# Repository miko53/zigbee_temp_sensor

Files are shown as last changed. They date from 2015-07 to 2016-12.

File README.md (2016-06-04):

# zigbee temperature sensor

This repository contains project about a temperature sensor based on Xbee device.
It will be coupled with the zigbee controler and the web_monitoring projets to resp. retrieve the value from the sensor 
and display thought a web site.

## Hardware part
The hardware folder groups schematics. it is based on a PIC device (PIC18LF2420) coupled with a XBee module (from Digi)
Temperature and Humidity sensor is a HYT221

## Firmware part
The folder contains source code to build the firmware for the PIC device.

## Features
 - read temperature and humidity around each minutes
 - read the battery voltage
 - PIC clock calibration
Most of 
 
##### Note:
 - acquisition period will be reviewed to improve consumption
 
autonomy test on going, with hourly reception of battery value and reception of temp/humidity each minutes
 - estimation: more than 6 months if I interpolate the current consumption.

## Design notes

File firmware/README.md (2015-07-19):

 zigbee_temp_sensor
code for manage temperature and humidity sensor with a PIC device and a Zigbee (Xbee device)

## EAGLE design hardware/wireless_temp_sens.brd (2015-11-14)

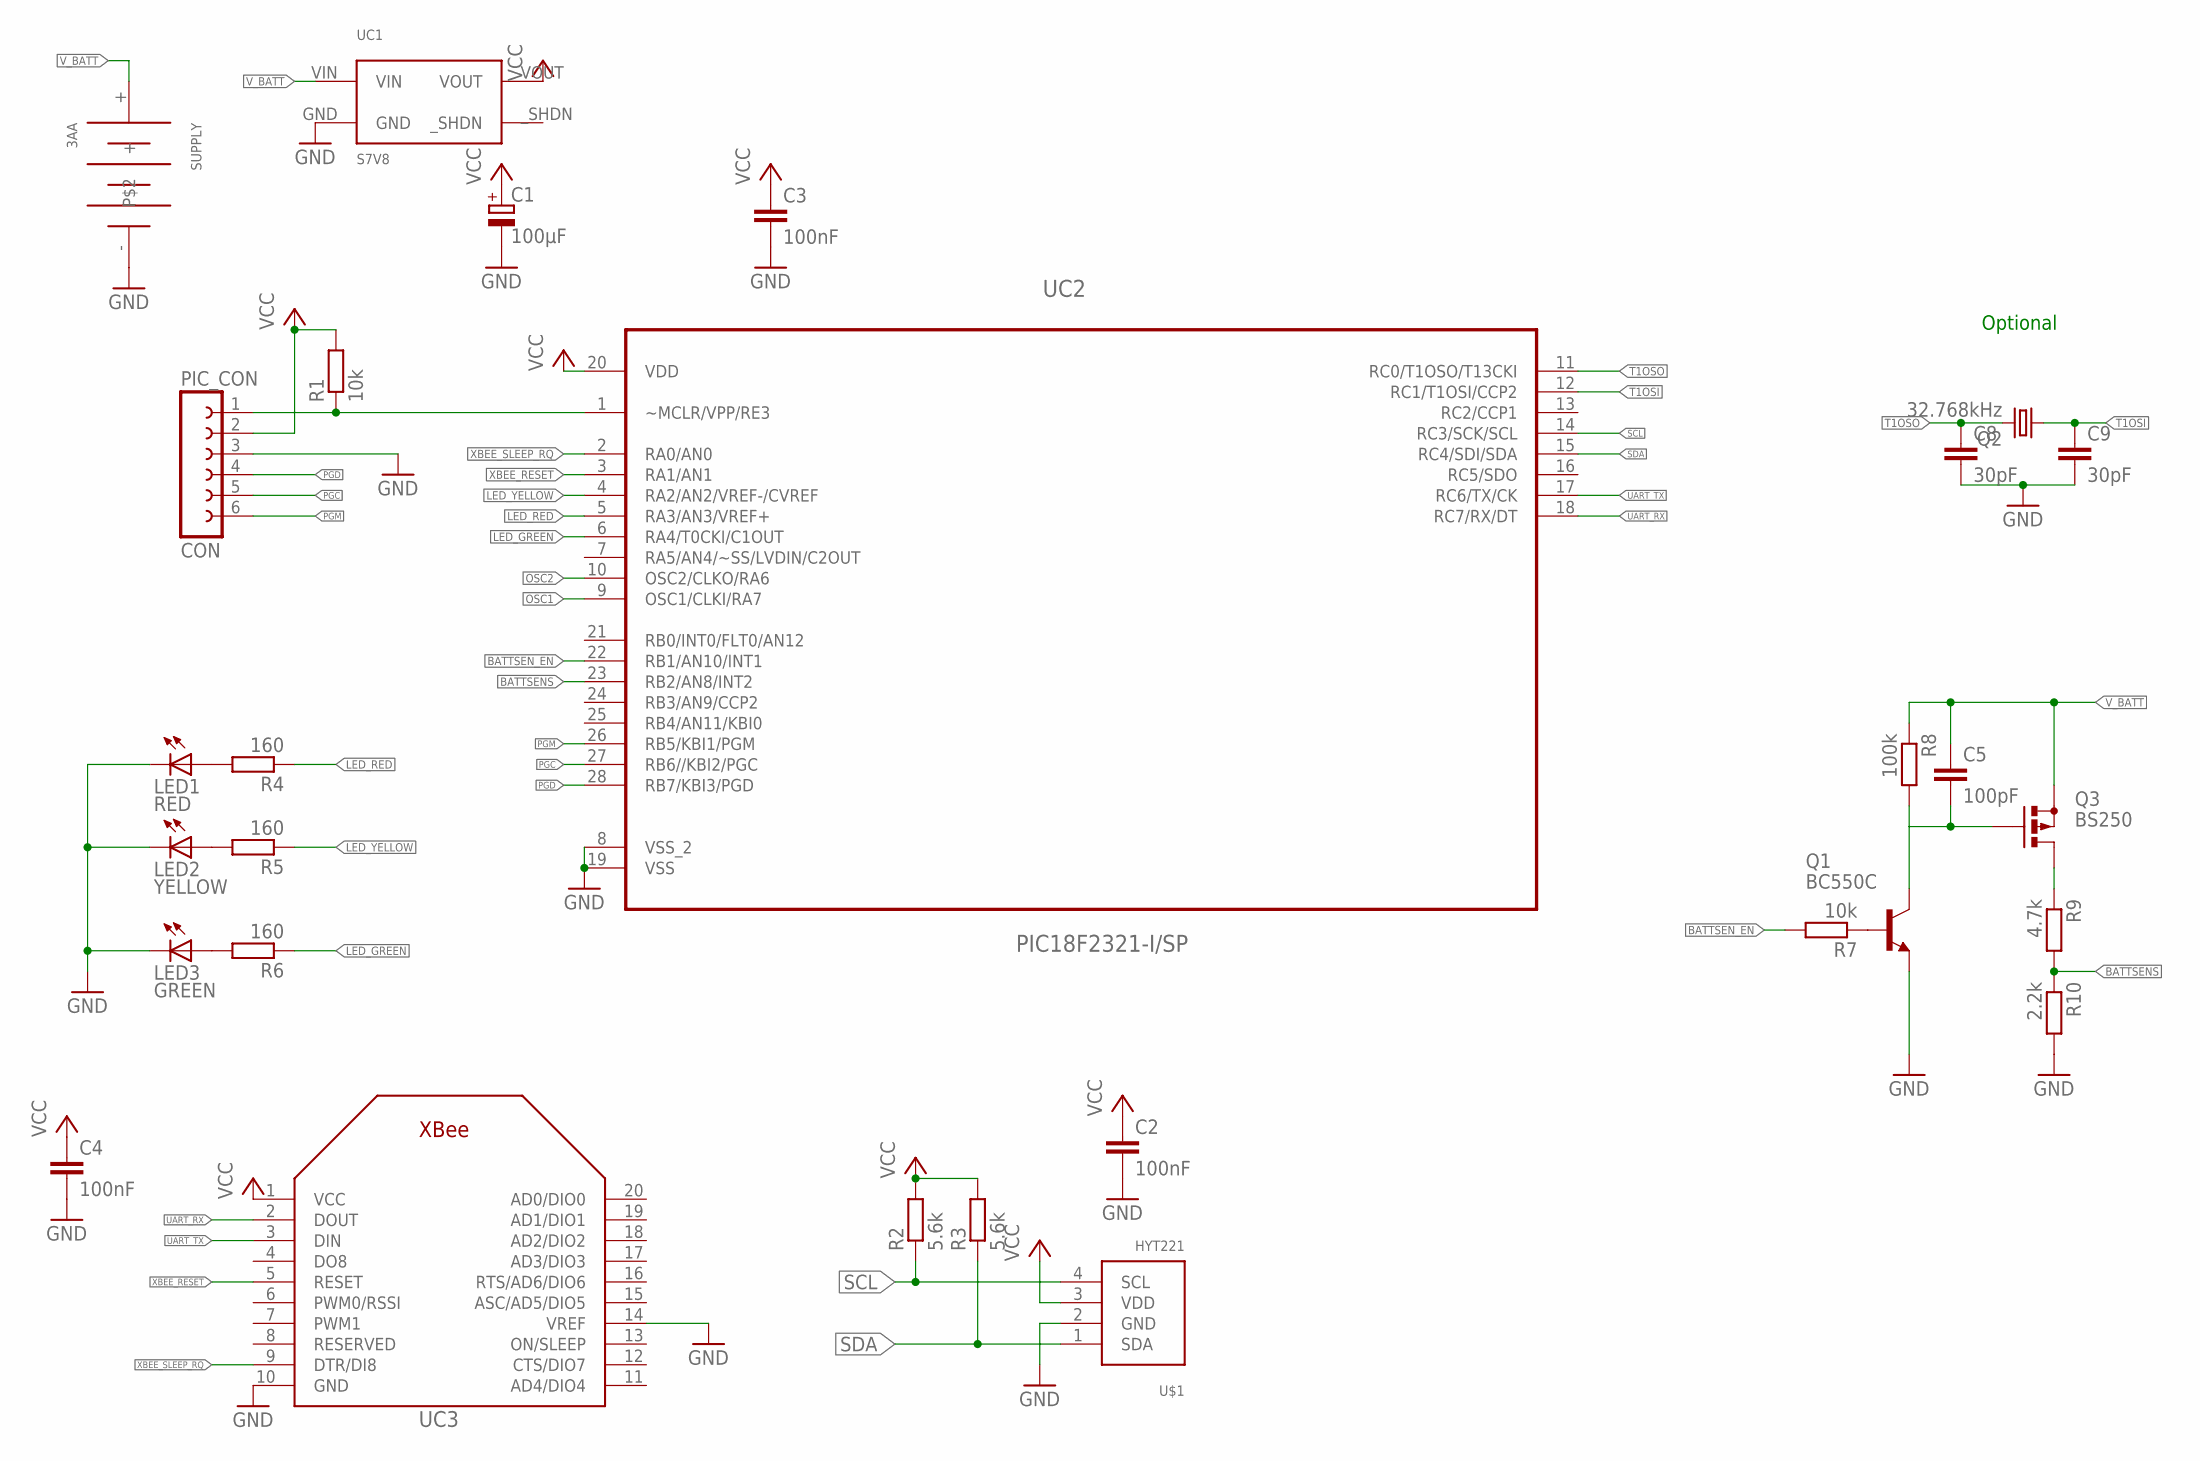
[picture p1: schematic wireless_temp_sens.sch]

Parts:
C1: 100µF; E2,5-6
C2, C3, C4: 100nF; C025-025X050
C5: 100pF; C025-025X050
C8, C9: 30pF; C025-024X044
CON: PIC_CON; FE06
LED1: RED; LED3MM
LED2: YELLOW; LED3MM
LED3: GREEN; LED3MM
Q1: BC550C; TO92-EBC
Q2: 32.768kHz; TC26H
Q3: BS250; SOT54E
R1, R7: 10k; 0204/7
R2, R3: 5.6k; 0204/7
R4, R5, R6: 160; 0204/7
R8: 100k; 0204/7
R9: 4.7k; 0204/7
R10: 2.2k; 0204/7
SUPPLY: 3AA; LR6-R6-R6P
U$1: HYT221HYT221-CON; HYT221-CON
UC1: S7V8; S7V8_P
UC2: PIC18F2321-I/SP; DIP254P762X508-28
UC3: XBEE

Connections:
BATTSENS: R9.2, R10.1, UC2.23 (RB2/AN8/INT2)
BATTSEN_EN: R7.2, UC2.22 (RB1/AN10/INT1)
GND: C1.-, C2.2, C3.2, C4.2, C8.2, C9.2, CON.3, LED1.K (C), LED2.K (C), LED3.K (C), Q1.E, R10.2, SUPPLY.-, U$1.2 (GND), UC1.GND, UC2.8 (VSS_2), UC2.19 (VSS), UC3.10 (GND), UC3.14 (VREF)
LED_GREEN: R6.1, UC2.6 (RA4/T0CKI/C1OUT)
LED_RED: R4.1, UC2.5 (RA3/AN3/VREF+)
LED_YELLOW: R5.1, UC2.4 (RA2/AN2/VREF-/CVREF)
unnamed: Q1.B, R7.1
unnamed: CON.1, R1.1, UC2.1 (~MCLR/VPP/RE3)
unnamed: Q3.D, R9.1
unnamed: C5.2, Q1.C, Q3.G, R8.2
unnamed: LED1.A, R4.2
unnamed: LED2.A, R5.2
unnamed: LED3.A, R6.2
OSC1: UC2.9 (OSC1/CLKI/RA7)
OSC2: UC2.10 (OSC2/CLKO/RA6)
PGC: CON.5, UC2.27 (RB6//KBI2/PGC)
PGD: CON.4, UC2.28 (RB7/KBI3/PGD)
PGM: CON.6, UC2.26 (RB5/KBI1/PGM)
SCL: R2.1, U$1.4 (SCL), UC2.14 (RC3/SCK/SCL)
SDA: R3.1, U$1.1 (SDA), UC2.15 (RC4/SDI/SDA)
T1OSI: C9.1, Q2.1, UC2.12 (RC1/T1OSI/CCP2)
T1OSO: C8.1, Q2.2, UC2.11 (RC0/T1OSO/T13CKI)
UART_RX: UC2.18 (RC7/RX/DT), UC3.2 (DOUT)
UART_TX: UC2.17 (RC6/TX/CK), UC3.3 (DIN)
VCC: C1.+, C2.1, C3.1, C4.1, CON.2, R1.2, R2.2, R3.2, U$1.3 (VDD), UC1.VOUT, UC2.20 (VDD), UC3.1 (VCC)
V_BATT: C5.1, Q3.S, R8.1, SUPPLY.+, UC1.VIN
XBEE_RESET: UC2.3 (RA1/AN1), UC3.5 (RESET)
XBEE_SLEEP_RQ: UC2.2 (RA0/AN0), UC3.9 (DTR/DI8)

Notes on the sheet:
Optional

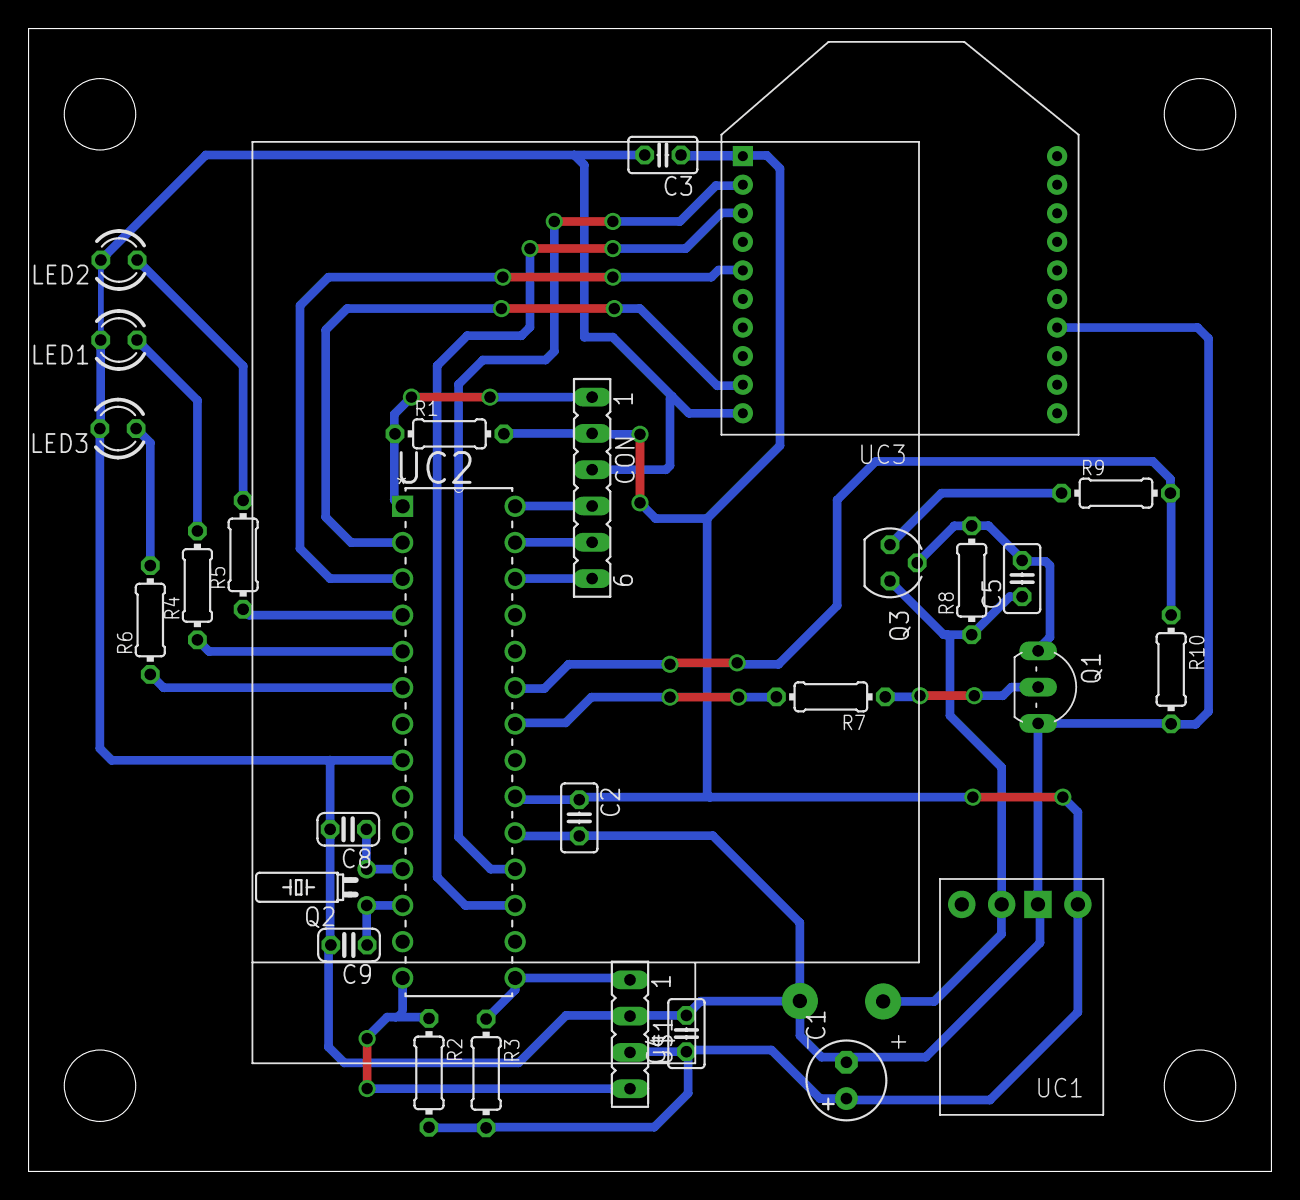
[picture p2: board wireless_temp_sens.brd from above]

Board: 2 copper layers, 87.0 x 80.0 mm, 29 parts (0 on the bottom side), 26 nets.

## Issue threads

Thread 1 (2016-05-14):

current consumtion to high

miko53, 2016-05-14:
some improvement to done on this

- remove polling to 500ms for waiting ZB emission, do some try to test the emission of data before sleep (normally ZB do sleep when data are sent)
- extends battery checks, each 5min seems too short
- try to wake ZB module the min has possible.

miko53, 2016-05-16:
1st &and 3rd done
Test on-going.

miko53, 2016-06-04:
Now I obtain more reasonable value, still under test.

Closed 2016-06-04.

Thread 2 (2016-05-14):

frame error not managed

miko53, 2016-05-14:
When a frame error occurs on serial line with ZB, that's means that the internal RC clock has derived and a re-calibration must be done.
 - the code for this must be added.

miko53, 2016-05-16:
Today a very simple management, --> do a reset() because the recalibration is done at boot so it should normally work

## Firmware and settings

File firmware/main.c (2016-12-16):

#include <xc.h>
#include "config.h"
#include "global.h"
#include "uart.h"
#include "zb_handle.h"
#include "status.h"
#include "leds.h"
#include "i2c.h"
#include "hyt221.h"
#include "osc.h"
#include "timer.h"

#define     BATT_COUNTER_MAX      (4*(60)) //number of deep sleep around 4hour
#define     ZB_JOINED_COUNTER_MAX (100) //around 52s

typedef enum
{
  NOT_JOINED,
  JOINED
} zb_stateT;

typedef enum
{
  LAUNCH_ACQ,
  SLEEP,
  WAIT_HYT221_ACQ,
  SEND_DATA,
} main_stateT;

static zb_stateT zb_state;
static main_stateT main_state;

static uint16_t batt_value;
static uint24_t batt_counter;
static uint8_t wait_join_counter;

static void batt_launch_acq();
static void main_loop();

int main(void)
{
  OSCTUNE = 0x00;
  //set up internal clock to 1MHz
  OSCCON  = 0x40;

  //configure PORT A in output for led display and zigbee mngt
  PORTA = 0x0;
  TRISA = 0x0;

  //configure unused ports in output to low level to minimize the consumption
  TRISBbits.RB0 = 0;
  PORTBbits.RB0 = 0;
  TRISBbits.RB3 = 0;
  PORTBbits.RB3 = 0;
  TRISBbits.RB4 = 0;
  PORTBbits.RB4 = 0;
  TRISCbits.RC2 = 0;
  PORTCbits.RC2 = 0;
  TRISCbits.RC5 = 0;
  PORTCbits.RC5 = 0;

  //activate to read the batt voltage
  PORTBbits.RB1 = 0; //set BATT_ENABLE bit to 0 (no active)
  TRISBbits.RB1 = 0; //set RB1 in OUTPUT (BATT ENABLE)
  TRISBbits.RB2 = 1; //set RB2 in INPUT (AN8)
  PIR1bits.ADIF = 0; //set A/D buffer to empty
  PIE1bits.ADIE = 1; //enable A/D interrupt

  __delay_ms(5);
  //T1CON = 0x0F;
  calibration();
  //OSCTUNE = 0;
  //__delay_ms(5);
  //T1CON = 0;

  i2c_setup();
  uart_setup();

  INTCONbits.PEIE = 1; //activate peripherical interrupt
  INTCONbits.GIE = 1; //activate global interrupt

  XBEE_WAKE_UP();
  XBEE_RESET_ON();
  XBEE_RESET_OFF();

  main_loop();
  return 0;
}

static void main_loop()
{
  zb_statusT zb_status;
  STATUS_T hyt221_status;

  batt_counter = BATT_COUNTER_MAX;
  wait_join_counter = 0;

  zb_state = NOT_JOINED;
  main_state = LAUNCH_ACQ;

  leds_glitch(LED_GREEN);

  while (1)
  {
    zb_handle();
    zb_status = zb_handle_getStatus();
    switch (zb_status)
    {
      case ZB_STATUS_NOT_JOINED:
        zb_state = NOT_JOINED;
        main_state = LAUNCH_ACQ;
        XBEE_WAKE_UP(); //just in case receiving NOT_JOINED but go to sleep, must be not occurs...
        //leds_glitch(LED_YELLOW);
        timer0_wait_262ms();
        timer0_wait_262ms();
        break;

      case ZB_STATUS_JOINED:
        zb_state = JOINED;
        break;

      default:
        break;
    }

    switch (zb_state)
    {
      case JOINED:
        switch (main_state)
        {
          case LAUNCH_ACQ:
            zb_handle_resetStatus();

            batt_counter++;
            if (!(batt_counter < BATT_COUNTER_MAX))
            {
              batt_counter = 0;
              batt_launch_acq();
            }

            hyt221_status = hyt221_launch_acq();
            if (hyt221_status == STATUS_OK)
            {
              main_state = WAIT_HYT221_ACQ;
            }
            else
            {
              leds_glitch(LED_GREEN | LED_YELLOW);
            }
            break;

          case WAIT_HYT221_ACQ:
            timer0_wait_65ms();
            hyt221_status = hyt221_operation();
            if (hyt221_status == STATUS_OK)
            {
              XBEE_WAKE_UP(); //XBee end of sleep request
              timer0_wait_262ms(); //waiting Xbee poll request and reply
              main_state = SEND_DATA;
            }
            else if (hyt221_status == STATUS_ERROR)
            {
              leds_glitch(LED_RED);
              main_state = LAUNCH_ACQ;
            }
            //default case not written
            //keep in state to wait and retry
            break;

          case SEND_DATA:
            //prepare and send data
            zb_handle_setTempRaw(hyt221_getTemp());
            zb_handle_setHumidityRaw(hyt221_getHumidity());
            zb_handle_sendData();
            //BOOL bAckReceived;
            /*bAckReceived = */
            zb_handle_waitAck(); //wait around 500ms to send DATA frame
            /*if (bAckReceived == FALSE)
            {
              //leds_glitch(LED_YELLOW | LED_GREEN);
              zb_handle_sendDbgData();
              timer0_wait_262ms();
            }*/
            main_state = SLEEP;
            break;

          case SLEEP:
            XBEE_SLEEP_RQ(); //XBee sleep request
            //sleep around 1min
            DEEP_SLEEP();
            main_state = LAUNCH_ACQ;
            break;

          default:
            break;
        }

        break;

      case NOT_JOINED:
      default:
        wait_join_counter++;
        if (wait_join_counter >= ZB_JOINED_COUNTER_MAX)
        {
          wait_join_counter = 0;
          XBEE_SLEEP_RQ(); //XBee sleep request
          //sleep around 1min
          DEEP_SLEEP();
          //leds_glitch(LED_YELLOW|LED_RED);
        }
        break;
    }
  }
}

static void batt_launch_acq()
{
  LATBbits.LATB1 = 1; //activate batt_sensor
  ADCON1 = 0x00; //Vss & Vdd src reference, only AN0
  ADCON0 = 0x20; //disable and select AN8
  ADCON2 = 0x8B; //right justifed, 2Tad, Frc
  ADCON0 |= 0x01; //start A/D movule
  ADCON0 |= 0x02 ; //start conversion

  IDLE_SLEEP();

  while ((ADCON0 & 0x02) == 0x02)
  {
    NOP();
  }

  batt_value = (ADRESH << 8) | ADRESL;
  LATBbits.LATB1 = 0; //desactivate batt_sensor
  ADCON0 &= ~0x01; //desactivate A/D converter
  zb_handle_setbatVolt(batt_value);
}

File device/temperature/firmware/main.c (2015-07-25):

#include <xc.h>
#include <stdint.h>
#include "config.h"
#include "leds.h"
#include "status.h"
#include "uart.h"
#include "i2c.h"
#include "global.h"
#include "zb_handle.h"
#include "hyt221.h"

//uint8_t nbCharRecu;
//static STATUS_T i2c_operation();
//static void wait_infinite();
//static void i2c_launch_acq();
//static void do_calculate_temp_humd();
//void i2c_main_loop();

static void main_loop();


int main(void)
{
  OSCTUNE = 0x00;
  //set up internal clock to 1MHz
  OSCCON  = 0x40;

  //configure PORT D in output for led display
  PORTD = 0x0;
  TRISD = 0x0;

  ///configure PORD B in output for zigbee mgt
  //set analog input into digital input
  ADCON1 = 0x05; //AN10(RB1)/AN11(RB4)/AN12(RB0)

  //put RB0 and RB1 in output
  //RB0 = _RESET
  //RB1 = SLEEP_RQ
  LATB = 0x01;
  TRISB = 0xFC;

  i2c_setup();
  uart_setup();
  
  //TIMER setup
  //1MHz --> 250kHz /2 --> 125kHz by 255  2.04ms
  //T0CON = 0xC0; // enable timer, 8bits timer
  //INTCONbits.TMR0IE = 1;

  INTCONbits.PEIE = 1; //activate peripherical interrupt
  INTCONbits.GIE = 1; //activate global interrupt

  //uint8_t requestHWversion[] =
  //{ 0x7e,  0x00, 0x04, 0x08 , 0x03, 'H', 'V', 0x56 };
  //uart_write(sizeof(requestHWversion), requestHWversion);

  //generate a reset of XBee module cycle time to 1MHZ give 4µs, the pulse must be at least 200ns
  LATBbits.LATB0 = 0;
  LATBbits.LATB0 = 1;

  main_loop();
}

typedef enum
{
  WAIT_JOINED,
  JOINED,
  SLEEP,
  WAIT_HYT221_ACQ,
} main_stateT;

static main_stateT main_state;
//static uint8_t wakeTick;
static void wait_endOfConversion(void);


static void main_loop()
{
  zb_statusT zb_status;
  STATUS_T hyt221_status;
  main_state = WAIT_JOINED;

  leds_green_glitch();

  while (1)
  {
      zb_handle();
      zb_status = zb_handle_getStatus();
      switch (zb_status)
      {
          case ZB_STATUS_NOT_JOINED:
              main_state = WAIT_JOINED;
              leds_yellow_glitch();
              __delay_ms(400); //400+100 in glitch func
              break;

          case ZB_STATUS_JOINED:
              if (main_state == WAIT_JOINED)
                main_state = JOINED;
              break;

          case ZB_STATUS_IN_ERROR:
              leds_red_glitch();
          default:
              break;
      }
      
      switch (main_state)
      {
          case WAIT_JOINED:
              break;

          case JOINED:
              hyt221_launch_acq();
              main_state = WAIT_HYT221_ACQ;
              break;

          case SLEEP:
              //sleep 1min
              LATBbits.LATB1 = 1; //sleep request
              WDTCONbits.SWDTEN = 1;
              SLEEP();
              WDTCONbits.SWDTEN = 0;
              LATBbits.LATB1 = 0; //end of sleep
              main_state = WAIT_JOINED;
              break;

          case WAIT_HYT221_ACQ:
              //__delay_ms(60);
              wait_endOfConversion();
              hyt221_status = hyt221_operation();
              if (hyt221_status == STATUS_OK)
              {
                  //send data
                  zb_handle_sendData(hyt221_getTemp(), hyt221_getHumidity());
                  //leds_green_glitch();
                  __delay_ms(500); //400  + 100 in glitch
                  main_state = SLEEP;
              }
              else if (hyt221_status == STATUS_ERROR)
              {
                  leds_red_glitch();
              }
              break;

          default:
              break;
      }
  }
}


static void wait_endOfConversion(void)
{
  T0CON = 0xC5; // enable timer, 8bits timer,prescaler to 64 for around 65ms
  INTCONbits.TMR0IE = 1; //active TIMER0 interupt.
  OSCCONbits.IDLEN = 1; //set Idle mode on Sleep instruction
  SLEEP(); //TODO check that end of idle mode on IT timer
  OSCCONbits.IDLEN = 0; //reset idle mode on sleep instruction
  T0CONbits.TMR0ON = 0; //stop timer
}

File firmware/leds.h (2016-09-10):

/*
 * File:   leds.h
 * Author: mickael
 *
 * Created on 6 avril 2015, 12:30
 */

#ifndef LEDS_H
#define	LEDS_H

#ifdef	__cplusplus
extern "C" {
#endif

#define     LED_YELLOW      (0x04)
#define     LED_RED         (0x08)
#define     LED_GREEN       (0x10)

extern void leds_glitch(uint8_t leds);

#ifdef	__cplusplus
}
#endif

#endif	/* LEDS_H */

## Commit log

2015-07-25 update, remove leds ON/OFF and put glith for consumption
2015-09-13 add first hardware version, not finished
    [wireless_temp_sens.brd, wireless_temp_sens.sch]
2015-09-20 update board schema
    [wireless_temp_sens.brd, wireless_temp_sens.sch]
2015-10-10 update schematic with G300 box
    [wireless_temp_sens.brd, wireless_temp_sens.sch]
2015-10-11 add 2.54mm connector for I2C
    [wireless_temp_sens.brd, wireless_temp_sens.sch]
2015-11-11 update schematcks (width, drill and voltage fct emplacement
    [wireless_temp_sens.brd, wireless_temp_sens.sch]
2015-11-14 update resitor value or A/D conversion and update brd to remove some vias
    [wireless_temp_sens.brd, wireless_temp_sens.sch]
2016-02-12 reorganize folder to insert web and controler app
    [wireless_temp_sens.brd, wireless_temp_sens.sch]
2016-05-05 add sleep mode with battery each 5min, + sleep mode when attempt to join
2016-05-16 some update on firmware code, put in idle in I2C operation, set at output some I/O, remove unnecessary loop and set ZB in sleep more long time
2016-06-04 fix consumption issue, the XBee module is not put in SLEEP state (wrong PIN used before)
    [main.c, uart.c, zb_handle.c]
2016-09-10 rework temperature,humidity formula. no more reset on Xbee disassociated, fix bug on Xbee sleep and Xbee status. Add more timeout for ack
    [hyt221.c, leds.h, main.c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]
2016-09-11 modify RED led by GREEN led at start-up, add laucnh-acq on reset
    [main.c]
2016-12-16 add under compilation flag possibility to send debug frame, simplificate management when XBEE lost network, check battery for 4 hours instead of one.
